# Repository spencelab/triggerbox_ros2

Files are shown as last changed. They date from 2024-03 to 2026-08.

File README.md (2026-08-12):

# To run it
Physical trigger pulses are enabled by default for backward compatibility:
```
ros2 run triggerbox_ros2 triggerbox_host
```
To start with the physical output blanked instead:
```
ros2 run triggerbox_ros2 triggerbox_host \
  --ros-args \
  -p output_enabled_on_start:=false
```
To change the frame rate
```
ros2 service call /triggerbox_host/set_framerate triggerbox_ros2_interfaces/srv/SetFramerate "{data: 250.0}"
```
# Porting to ROS2
## 20260522 Putting v14 on triggerbox arduino off camdev ubuntu 24
Just worked... but more arduino pfaff than would like. And DONT install the full fuse or it reverts you to fuse 2... ooops i did that on my dev machine.
1. Download arduino 2 IDE appimage or zip. put in ~/Applications/Ard...
2. Make the executable executable w permission in gui right click
3. Add yuor user to dialout group and log in log out so you can access serial
4. install the fuse thing and do other thigns to make the IDE work
```
sudo apt install libfuse2t64

cd ~/Applications/arduino-ide_2.3.8_Linux_64bit
sudo chown root:root chrome-sandbox
sudo chmod 4755 chrome-sandbox
ls -l chrome-sandbox

cat > ~/.local/share/applications/arduino-ide-2.desktop <<'EOF'
[Desktop Entry]
Type=Application
Name=Arduino IDE 2
Comment=Arduino development environment
Exec=/home/spencelab/Applications/arduino-ide_2.3.8_Linux_64bit/arduino-ide
Icon=/home/spencelab/Applications/arduino-ide_2.3.8_Linux_64bit/resources/app/resources/icons/512x512.png
Terminal=false
Categories=Development;IDE;Electronics;
StartupNotify=true
EOF

chmod +x ~/.local/share/applications/arduino-ide-2.desktop
update-desktop-database ~/.local/share/applications 2>/dev/null || true

sudo usermod -a -G dialout $USER

#log out, log back in again

Do this:

Open Show Apps
Search Arduino
Right-click Arduino IDE 2
Choose Add to Favorites

That should pin it to the left dock.

./arduino-ide
```

I copied the UDEV library to triggerbox_ros2 repo to ~/Arduino/libraries/UDEV/UDEV.cpp[h] and it just worked and could flash the arduino. 

I pulled the latest triggerbox host and colcon build and it just ran. I use `enable_output` service to turn on pulses. 100Hz works great.

Now on to setting up arduino_udev_ros2 from scratch on this machine. Writing guide on that repo README.

## 20260521 Output Pulse Enable Disable now working for streaming v14 firmware

For continuous recording, we want to start all the camera nodes and put in hardware trigger mode and have them waiting, and then start the pulses from the triggerbox. That way all cameras should start on the same frame no matter when ROS2 messages might arrive, if we did it with software. So we made the patch below and introdcued v14 firmware. Tested at home with oscilloscope with Arduino Nano `trig9`. Also flashed the firmware in Linux using Arduino 2.3.8 IDE AppImage. Needed (Old Bootloader) in Nano spec. 

Also added specifying the device eg `/dev/trig9` in the triggerbox_host launch. Notes in https://chatgpt.com/g/g-p-6a03947397fc8191b3298417bda72197-camera-ros2-contin/c/6a0394fa-c8ec-83ea-a1c0-96703d8dfd53.

Commands to test pulse enable/disable: (trig9=ttyUSB0)
```
~/ros2_ws/src/triggerbox_ros2/scripts/get_triggerbox_name_version /dev/ttyUSB0
ros2 run triggerbox_ros2 triggerbox_host /dev/trig9
ros2 service list | grep triggerbox_host
ros2 topic list | grep output_enabled
ros2 topic echo /triggerbox_host/output_enabled
ros2 service call /triggerbox_host/enable_output std_srvs/srv/Trigger "{}"
# CONFIRMED ON OSCILLOSCOPE 100HZ PULSES on D9 STARTED!
ros2 service call /triggerbox_host/disable_output std_srvs/srv/Trigger "{}"
ros2 service call /triggerbox_host/set_output_enabled std_srvs/srv/SetBool "{data: true}"
ros2 service call /triggerbox_host/set_output_enabled std_srvs/srv/SetBool "{data: false}"
```
Intended rig sequence:
1. Start triggerbox_host.
2. It sets FPS and starts Timer1 clock, but output is blanked.
3. Wait for clock model estimate.
4. Configure/start all camera recorders.
5. Call /triggerbox_host/enable_output.
6. Record.
7. Call /triggerbox_host/disable_output.
8. Stop camera recorders.

## 20260520 Getting to work on fresh ubuntu 24 camdev in lab
1. clone this repo into ros2_ws/src
2. **NEED** to also clone triggerbox_ros2_interfaces
3. then colcon build will do both and you and try with `source install/setup.bash` then `ros2 run triggerbox_ros2 triggerbox_host`.
4. you will likely have errors due to no python serial library OR your user spencelab not having been added to dialout.
5. if former, try `sudo apt install python3-serial`
6. if latter, try `sudo adduser spencelab dialout` and then reboot.
7. This code expects and will exit with error if arduino does not have version 13 firmware. (assert in triggerbox_device.py).
8. I wrote a script in this repo to check if an arduino is flashed with triggerbox by asking for name and version using it's handshaking protocol. it's an executable. call with `./get_triggerbox_name_version` or `./get_triggerbox_name_version /dev/ttyACM0` etc. Gives:

```
spencelab@ros2test:~/ros2_ws/src/triggerbox_ros2/scripts$ ./get_triggerbox_name_version 
Phase 1: udev/name handshake at 9600
name raw: b'trig1\x00\x00\x00DB'
name: trig1
crc ok: True

Phase 2: triggerbox firmware version at 115200
attempt 1: no V packet yet
attempt 2: no V packet yet
attempt 3: no V packet yet
attempt 4: no V packet yet
attempt 5: no V packet yet
attempt 6: no V packet yet
attempt 7: no V packet yet
attempt 8: no V packet yet
attempt 9: no V packet yet
Got V packet on attempt 10
payload length: 7
payload hex: 0D 0A 00 00 00 38 0B
checksum: 5a
version decimal=13, hex=0xD
value=13, pulsenumber=10, ticks=2872
```
9. The firmware included in this triggerbox_ros2 repo is for version 13.
10. In order to flash an arduino with this firmware version from ubuntu 24, you can do the following.
    1. Download install arduino IDE 2.3.8 or newer from arduino, i used appimage, had to properties make executable and `sudo apt install fuse`.
    2. Download the arduino_udev_ros2 repo from spencelab.
    3. Copy the UDEV library from arduino_udev_ros2 into the arduino IDE area `cp -r ~/arduino_udev_ros2/firmware/UDEV ~/Arduino/libraries/`
    4. Restart the IDE, maybe you can build triggerbox.ino?
    5. Yes! It works. I flashed an ancient Arduino Nano from home. It came up as `/dev/ttyUSB0` and caused an ubuntu system error when the UDEV rule failed, but no biggy. Had to choose Processer -> AtMega328P (Old Bootloader) for it to flash, otherwise Arduino IDE fell back to programmger and said no response. Awesome.
    6. Then it will still crash as it reads out garbage from EEPROM as the name 0xFF, but version was correct with new `get_triggerbox...` script. So you just need to set a name with: `arduino-udev-name /dev/ttyUSB0 --set-name trig9 --verbose`. i got back `
RAW: 0x4E 0x3D 0x74 0x72 0x69 0x67 0x39 0x0 0x0 0x0 0x43 0x37 
SET NAME: trig9 (0x74 0x72 0x69 0x67 0x39)
`
    7. The you can ping it! with any script.

```
spencelab@ros2test:~/ros2_ws/src/triggerbox_ros2/scripts$ ./get_triggerbox_name_version /dev/ttyUSB0
Phase 1: udev/name handshake at 9600
name raw: b'trig9\x00\x00\x00C7'
name: trig9
crc ok: True

Phase 2: triggerbox firmware version at 115200
attempt 1: no V packet yet
attempt 2: no V packet yet
attempt 3: no V packet yet
attempt 4: no V packet yet
attempt 5: no V packet yet
attempt 6: no V packet yet
attempt 7: no V packet yet
attempt 8: no V packet yet
attempt 9: no V packet yet
attempt 10: no V packet yet
attempt 11: no V packet yet
Got V packet on attempt 12
payload length: 7
payload hex: 0D 0C 00 00 00 F5 14
checksum: 22
version decimal=13, hex=0xD
value=13, pulsenumber=12, ticks=5365
```
11. You can use triggerbox_host in ROS2 with this package if you identify the triggerbox /dev/ttyACM0 etc. just fine. If you want the fancy mapping to it's given name, so it reliably appears as `/dev/trig2` and you can disambiguate it from eg the treadmill, which is really useful, you need to use arduino_udev and do a few more setup steps. Those are:
## 20260519 Getting to work with cambuffer_recorder_ng

Using arduino from my dev box with red proto board shield on top with driver chip and switch and one bnc.

It is flaky. With switch in 5V position (towards USB in jack) switch needs jiggling for to work. Too much time in bags.

But it will work and trigger the ximea nicely at 100hz.

To start it and change frame rat:
```
ros2 run triggerbox_ros2 triggerbox_host
ros2 service call /triggerbox_host/set_framerate triggerbox_ros2_interfaces/srv/SetFramerate "{data: 25.0}"
```

Figured out with
```
ros2 service type /triggerbox_host/set_framerate
ros2 interface show triggerbox_ros2_interfaces/srv/SetFramerate
```

## 20260521 Pulse Blanking Version 14 Patch and Test Instructions:

https://chatgpt.com/g/g-p-6a03947397fc8191b3298417bda72197/c/6a0394fa-c8ec-83ea-a1c0-96703d8dfd53

Yep, this is the right repo now. I made a focused patch for output blanking while the triggerbox clock keeps running.

Download the triggerbox output-blanking patch

What this adds

Firmware now has:

E0 = disable/blank physical trigger output while Timer1 keeps running
E1 = enable physical trigger output from Timer1

It bumps firmware version from:

13 → 14

so you can confirm the flashed firmware is the new one.

ROS2 host now adds services:

/triggerbox_host/set_output_enabled   std_srvs/srv/SetBool
/triggerbox_host/enable_output        std_srvs/srv/Trigger
/triggerbox_host/disable_output       std_srvs/srv/Trigger
/triggerbox_host/start_clock          std_srvs/srv/Trigger
/triggerbox_host/stop_clock           std_srvs/srv/Trigger

It also publishes:

/triggerbox_host/output_enabled       std_msgs/msg/Bool

Default behavior is:

Timer1 clock runs at configured FPS.
Physical trigger output starts ENABLED by default for backward compatibility.
The Timer1 clock and physical trigger pulses therefore begin immediately after startup/configuration.
Newer camera-control workflows may temporarily blank the physical output with disable_output and restore it with enable_output.

To opt into the former blanked-at-start behavior, launch with:

ros2 run triggerbox_ros2 triggerbox_host --ros-args -p output_enabled_on_start:=false
Branch and apply
cd ~/ros2_ws/src/triggerbox_ros2

git status
git switch main
git pull origin main

git switch -c output-blanking-clock-run
unzip -o /path/to/triggerbox_ros2_output_blanking_patch.zip

Build:

cd ~/ros2_ws

colcon build --packages-select triggerbox_ros2 \
  --event-handlers console_direct+

source install/setup.bash
Flash firmware

Copy/install the updated firmware/triggerbox/triggerbox.ino to Arduino IDE or open it directly.

After flashing, your checker should report:

version decimal=14, hex=0xE
Test services

Start host:

ros2 run triggerbox_ros2 triggerbox_host

Confirm services:

ros2 service list | grep triggerbox_host
ros2 topic list | grep output_enabled

Check output state:

ros2 topic echo /triggerbox_host/output_enabled

Enable physical trigger pulses:

ros2 service call /triggerbox_host/enable_output std_srvs/srv/Trigger "{}"

Disable physical trigger pulses:

ros2 service call /triggerbox_host/disable_output std_srvs/srv/Trigger "{}"

Or set directly:

ros2 service call /triggerbox_host/set_output_enabled std_srvs/srv/SetBool "{data: true}"
ros2 service call /triggerbox_host/set_output_enabled std_srvs/srv/SetBool "{data: false}"

Clock controls, mostly for debugging:

ros2 service call /triggerbox_host/start_clock std_srvs/srv/Trigger "{}"
ros2 service call /triggerbox_host/stop_clock std_srvs/srv/Trigger "{}"
Current rig behavior
1. Start triggerbox_host.
2. It sets FPS, starts Timer1, and enables physical trigger output by default.
3. Camera-control can blank output with /triggerbox_host/disable_output to define one shared hardware endpoint for synchronized RAM-buffer dumps.
4. After every camera finishes the dump write, camera-control calls /triggerbox_host/enable_output and acquisition continues.
Notes

This patch does not require changes to triggerbox_ros2_interfaces; it uses standard ROS services from std_srvs.

The default is now pulses on for backward compatibility with older acquisition software. Newer camera-control workflows explicitly blank and restore output around synchronized RAM-buffer dumps.

### Lots of fun profiling on hardware trigger.

Trying to get the thread rt priority:
```
spencelab@ros2test:~/ros2_ws$ sudo groupadd -f realtime
[sudo] password for spencelab: 
spencelab@ros2test:~/ros2_ws$ sudo usermod -aG realtime $USER
spencelab@ros2test:~/ros2_ws$ sudo tee /etc/security/limits.d/99-realtime.conf >/dev/null <<'EOF'
> @realtime   -   rtprio     80
@realtime   -   memlock    unlimited
@realtime   -   nice       -10
EOF
spencelab@ros2test:~/ros2_ws$ cat /etc/security/limits.d/99-realtime.conf 
@realtime   -   rtprio     80
@realtime   -   memlock    unlimited
@realtime   -   nice       -10
spencelab@ros2test:~/ros2_ws$ 
```

You need to reboot, but **THAT WORKS** and on reboot, running in terminal with no browser open, it dumps to disk with 16 frame ximea buffer and we had ZERO frame drops at the camera for 30 seconds or a minute or so. GREAT! And even cooler you can see the buffer working. camera triggers are on sync but a lag in disk writing follow by catching up!



See it should be around 10ms, it lags off to 47ms and then a series of 1ms writes catch up!

## Older work
1. Just get triggerbox_device.py to work in Python3
2. On Spence mac...
3. pip3 install ... no it says use brew... brew... tricky... so

```
conda create -f triggerbox_ros2
conda activate triggerbox_ros2
conda install pyserial numpy
python3 triggerbox_device.py /dev/tty.usbmodem1101 
```

Made Queue queue for python3...
exceptions parentheses...

4. Copied arduinoudev.py from our forked repo into '/Users/aspence/miniconda3-arm64/envs/triggerbox_ros2/lib/python3.12/site-packages/arduinoudev.py' because lazy. It has a setup.py... you could probably conda install from setup.py the package and it would put there for you...
5. It runs! Fixing all the Queue to queue...
6. 

## Getting running on the lenovo box with trig5 arduino

1. Forgot to commit setup.cfg so it couldnt' find triggerbox_host executable... fixed.
2. Didn't have serial... did

```
spencelab@ros2test:~/ros2_ws$ rosdep install --from-paths src -y --ignore-src
executing command [sudo -H apt-get install -y python3-serial]
Reading package lists... Done
Building dependency tree... Done
Reading state information... Done
Suggested packages:
  python3-wxgtk3.0 | python3-wxgtk
The following NEW packages will be installed:
  python3-serial
0 upgraded, 1 newly installed, 0 to remove and 0 not upgraded.
Need to get 78.7 kB of archives.
After this operation, 470 kB of additional disk space will be used.
Get:1 http://us.archive.ubuntu.com/ubuntu jammy/main amd64 python3-serial all 3.5-1 [78.7 kB]
Fetched 78.7 kB in 0s (268 kB/s)          
Selecting previously unselected package python3-serial.
(Reading database ... 294264 files and directories currently installed.)
Preparing to unpack .../python3-serial_3.5-1_all.deb ...
Unpacking python3-serial (3.5-1) ...
Setting up python3-serial (3.5-1) ...
#All required rosdeps installed successfully
```
### Access to serial port
Gah close need to do that dialout group user add jawn probably

```
serial.serialutil.SerialException: [Errno 13] could not open port /dev/ttyACM0: [Errno 13] Permission denied: '/dev/ttyACM0'
Traceback (most recent call last):
```
Fixed!

Find your groups `groups spencelab`

Does not include dialout.

`sudo adduser spencelab dialout`

**REBOOT** the machine! Logging in and out is not enough!

New error...

### It's running!

But I think my topics are missing the node name in front etc. ALSO must always remember to `. install/setup.bash`!

So i get now: (NOTES ABOUT THIS: I HAD HARDCODED NEW TOPIC NAMES WITH NO BASE. NOW Fixed below.).
```
spencelab@ros2test:~/ros2_ws$ . install/setup.bash 
spencelab@ros2test:~/ros2_ws$ ros2 topic list
/aout_confirm
/aout_raw
/aout_volts
/expected_framerate
/parameter_events
/pause_and_reset
/raw_measurements
/rosout
/set_triggerrate
/time_model
spencelab@ros2test:~/ros2_ws$ ros2 topic list -t
/aout_confirm [triggerbox_ros2_interfaces/msg/AOutConfirm]
/aout_raw [triggerbox_ros2_interfaces/msg/AOutRaw]
/aout_volts [triggerbox_ros2_interfaces/msg/AOutVolts]
/expected_framerate [std_msgs/msg/Float32]
/parameter_events [rcl_interfaces/msg/ParameterEvent]
/pause_and_reset [std_msgs/msg/Float32]
/raw_measurements [triggerbox_ros2_interfaces/msg/TriggerClockMeasurement]
/rosout [rcl_interfaces/msg/Log]
/set_triggerrate [std_msgs/msg/Float32]
/time_model [triggerbox_ros2_interfaces/msg/TriggerClockModel]
spencelab@ros2test:~/ros2_ws$ ros2 topic echo /raw_measurements 
start_timestamp: 1712791137.2870135
pulsenumber: 10550
fraction_n_of_255: 110
stop_timestamp: 1712791137.2923086
---
start_timestamp: 1712791138.2945035
pulsenumber: 10650
fraction_n_of_255: 18
stop_timestamp: 1712791138.2998571
---
start_timestamp: 1712791139.3024065
pulsenumber: 10751
fraction_n_of_255: 191
stop_timestamp: 1712791139.3076122
---
start_timestamp: 1712791140.3100817
pulsenumber: 10852
fraction_n_of_255: 103
stop_timestamp: 1712791140.3148384
---
start_timestamp: 1712791141.318424
pulsenumber: 10953
fraction_n_of_255: 33
stop_timestamp: 1712791141.3223727
---
^Cspencelab@ros2test:~/ros2_ws$ ros2 topic echo /time_model
gain: 0.010010829431015212
offset: 1712791031.6713433
---
gain: 0.010010877060864001
offset: 1712791031.671114
---
gain: 0.01001086394535979
offset: 1712791031.6712198
---
gain: 0.010010850077359702
offset: 1712791031.6713362
---

```

But this page makes me think I should have node names before topics etc. (https://docs.ros.org/en/humble/Tutorials/Beginner-CLI-Tools/Understanding-ROS2-Topics/Understanding-ROS2-Topics.html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)

YES! For rqt to see your custom message types and thus display them in the topic monitor you must do `. install/setup.bash` before `rqt` then it works.

It's publishing to /time_model

### 2025-06-30 Re-up working!

Ok I tried to do this again and had some issues with make_ros_topic - it was trying to make a topci `~time_model` in old school ros1 and ros2 requires the slash `~/time_model`. So i deleted the bit in make_ros_topic in triggerbox_host i believe so it just always adds slash, and it works! In ubuntu 22 on the testing lenovo. i flashed a freqsh v=13 firmware triggerbox onto the vilros test plate that had a EMG board on it. works great. i get:

```
spencelab@ros2test:~/ros2_ws/src/triggerbox_ros2$ ros2 run triggerbox_ros2 triggerbox_host 
INFO:trigger.device:Waiting until serial device confirmed...
INFO:root.serial:connected to device named ''
INFO:root.serial:checking firmware version
INFO:root.serial:checking firmware version
INFO:root.serial:checking firmware version
INFO:root.serial:checking firmware version
INFO:root.serial:checking firmware version
INFO:root.serial:checking firmware version
INFO:root.serial:checking firmware version
INFO:root.serial:checking firmware version
INFO:root.serial:checking firmware version
INFO:root.serial:connected to triggerbox firmware version 13
WARNING:root.serial:No clock measurements until framerate set.
[INFO] [1751303284.935785077] [triggerbox_host]: triggerbox_host: connected to 'v:13' on device '/dev/ttyACM0'
[INFO] [1751303284.937879748] [triggerbox_host]: triggerbox_host: setting FPS to 100.0
INFO:trigger.device:received set_triggerrate command with target of 100.0
[INFO] [1751303284.938357361] [triggerbox_host]: Got clock model
INFO:trigger.device:desired rate 100.0 (actual rate 100.0) using ICR1_AND_PRESCALER 0x9C4 64
[INFO] [1751303284.944930972] [triggerbox_host]: Got clock model
[INFO] [1751303284.945395432] [triggerbox_host]: triggerbox_host: waiting for clockmodel estimate
[INFO] [1751303285.447141439] [triggerbox_host]: triggerbox_host: waiting for clockmodel estimate
[INFO] [1751303285.949792132] [triggerbox_host]: triggerbox_host: waiting for clockmodel estimate
[INFO] [1751303286.452211598] [triggerbox_host]: triggerbox_host: waiting for clockmodel estimate
[INFO] [1751303286.954629185] [triggerbox_host]: triggerbox_host: waiting for clockmodel estimate
[INFO] [1751303287.456994117] [triggerbox_host]: triggerbox_host: waiting for clockmodel estimate
[INFO] [1751303287.959343659] [triggerbox_host]: triggerbox_host: waiting for clockmodel estimate
[INFO] [1751303288.460215038] [triggerbox_host]: triggerbox_host: waiting for clockmodel estimate
[INFO] [1751303288.897180485] [triggerbox_host]: Got clock model
DEBUG:trigger.device:approximate timer frequency: 99.89752418542193
[INFO] [1751303288.962573438] [triggerbox_host]: triggerbox_host: got clockmodel estimate
[INFO] [1751303289.910580327] [triggerbox_host]: Got clock model
DEBUG:trigger.device:approximate timer frequency: 99.88166720912373
[INFO] [1751303290.922867025] [triggerbox_host]: Got clock model
DEBUG:trigger.device:approximate timer frequency: 99.89321736840478
[INFO] [1751303291.936306345] [triggerbox_host]: Got clock model
DEBUG:trigger.device:approximate timer frequency: 99.88989040058513
[INFO] [1751303292.849422258] [triggerbox_host]: Got clock model
DEBUG:trigger.device:approximate timer frequency: 99.89887679263718
[INFO] [1751303293.863421914] [triggerbox_host]: Got clock model
DEBUG:trigger.device:approximate timer frequency: 99.89064213871087
[INFO] [1751303294.874911549] [triggerbox_host]: Got clock model
DEBUG:trigger.device:approximate timer frequency: 99.88857880865557
[INFO] [1751303295.888662594] [triggerbox_host]: Got clock model
DEBUG:trigger.device:approximate timer frequency: 99.89177746523458
[INFO] [1751303296.902946154] [triggerbox_host]: Got clock model
DEBUG:trigger.device:approximate timer frequency: 99.88764501523428
[INFO] [1751303297.917656235] [triggerbox_host]: Got clock model
DEBUG:trigger.device:approximate timer frequency: 99.88722978585729
[INFO] [1751303298.931940264] [triggerbox_host]: Got clock model
DEBUG:trigger.device:approximate timer frequency: 99.88824280233169
[INFO] [1751303299.946035008] [triggerbox_host]: Got clock model
DEBUG:trigger.device:approximate timer frequency: 99.88938141739722
[INFO] [1751303300.960263708] [triggerbox_host]: Got clock model
DEBUG:trigger.device:approximate timer frequency: 99.88931348767154
[INFO] [1751303301.972255338] [triggerbox_host]: Got clock model
DEBUG:trigger.device:approximate timer frequency: 99.88918245366627
[INFO] [1751303302.985092249] [triggerbox_host]: Got clock model
DEBUG:trigger.device:approximate timer frequency: 99.88966828749199
[INFO] [1751303303.998031260] [triggerbox_host]: Got clock model
DEBUG:trigger.device:approximate timer frequency: 99.88779585205677
[INFO] [1751303305.010649616] [triggerbox_host]: Got clock model
DEBUG:trigger.device:approximate timer frequency: 99.88689567203292
[INFO] [1751303306.024470742] [triggerbox_host]: Got clock model
DEBUG:trigger.device:approximate timer frequency: 99.88701791387936
[INFO] [1751303307.040632250] [triggerbox_host]: Got clock model
DEBUG:trigger.device:approximate timer frequency: 99.88776427283234
```

Now examining the topics: in second terminal:

```
spencelab@ros2test:~$ ros2 topic list
/parameter_events
/rosout
/triggerbox_host/aout_confirm
/triggerbox_host/aout_raw
/triggerbox_host/aout_volts
/triggerbox_host/expected_framerate
/triggerbox_host/pause_and_reset
/triggerbox_host/raw_measurements
/triggerbox_host/set_triggerrate
/triggerbox_host/time_model
```

works! to see need . install:

```
spencelab@ros2test:~$ ros2 topic echo /triggerbox_host/time_model 
The message type 'triggerbox_ros2_interfaces/msg/TriggerClockModel' is invalid
spencelab@ros2test:~$ pwd
/home/spencelab
spencelab@ros2test:~$ cd ros2_ws/
spencelab@ros2test:~/ros2_ws$ . install/setup.
bash: install/setup.: No such file or directory
spencelab@ros2test:~/ros2_ws$ . install/setup.bash 
spencelab@ros2test:~/ros2_ws$ ros2 topic list
/parameter_events
/rosout
/triggerbox_host/aout_confirm
/triggerbox_host/aout_raw
/triggerbox_host/aout_volts
/triggerbox_host/expected_framerate
/triggerbox_host/pause_and_reset
/triggerbox_host/raw_measurements
/triggerbox_host/set_triggerrate
/triggerbox_host/time_model
spencelab@ros2test:~/ros2_ws$ ros2 topic echo /triggerbox_host/time_model 
gain: 0.010011299331848193
offset: 1751303552.5350645
---
gain: 0.010011296453507578
offset: 1751303552.5350807
---
gain: 0.010011285478196099
offset: 1751303552.5351677
---
gain: 0.01001133854431243
offset: 1751303552.534838
```

### 2025-06-27 Spence using to test and set up big grey triggerbox with 8 bncs and IR

See the Strawlab_triggerbox wiki page on aspence/spencelab wiki for details. Basically flashed the firmware, changed to trig2, which based on the merb launch file might match the box there, helping with direct swap. Also confirmed in the launch file we want to run a triggerbox_host.

Using the ubuntu 22 test lenovo box, was able to set it's name, and python3 triggerbox_device, but when i did

```
cd ros2_ws
. install/setup.bash
ros2 run triggerbox_ros2 triggerbox_host
```

I get an error about an invalid topic name becuase of a ~. But my notes above suggest I had it working. How? Where?

```
In ROS 2, a topic name starting with a tilde (~) signifies a private namespace. This means the topic name will be resolved relative to the node's name, essentially using the node's name as a namespace. For instance, if you have a node named my_node and you publish to a topic named ~topic, the actual topic name will be /my_node/topic. 
However, the ROS 2 documentation mentions a specific rule for topic names starting with a tilde: they must be separated from the rest of the name with a forward slash (/). So, the correct syntax is ~/foo and not ~foo. This rule is in place to prevent inconsistencies with how ~foo is interpreted in filesystem paths. 
Therefore, the error you are encountering with ros2 topic likely stems from using ~nodename instead of ~/nodename when specifying a private topic name. You need to include the forward slash after the tilde to indicate a private namespace.
In summary:
~ indicates a private namespace, according to Duckietown.
~/topic_name is the correct syntax for a private topic, according to ROS2 Design.
Without the forward slash (~), ROS 2 might interpret the tilde differently or throw an error due to the syntax rule. 
To fix the issue, ensure you are using the correct syntax ~/topic_name when referring to private topics within ros2 topic commands.
```

Well I dont want a private name space. And above I said it was publishing to /time_model. I think the problem is that we are trying to create a bunch of `~time_model` type topics and that's not allowed in ROS2. Was it in ROS1?

```
def _make_ros_topic(base, other):
    if base == '~':
        return base+other

    #ensure no start slash and one trailing slash
    if base[0] == '/':
        base = base[1:]
    if base[-1] == '/':
        base = base[:-1]

    return base + '/' + other
```

I think it should just be /triggerbox_host/time_model etc? Above i just had /time_model in the root space. What do I get in the normal working ROS1 space?

See here:
https://github.com/aspence/spencelab/wiki/Ubuntu-22-Jammy-ROS-2-Humble-Testing

Yeah on ROS1 we get /triggerbox_node/time_model etc:

how and why? base name gets set to triggerbox_node. launch file? Yep looks like it:

from a ros 1 launch file:

```
- <node machine="tmill4merb" name="triggerbox_node" pkg="triggerbox"
    type="triggerbox_host" args="--device /dev/trig2" />
```

Now is the ros1 triggerbox_host.py code differetn wrt base name? No... but initializing different.

Maybe ROS1 takes ~time_model and makes it /NODE_NAME/time_model

I FIXED ALL ABOVE SEE ABOVE. Just commented out the base combine thing without ~. It just worked.

## Trigger output blanking

Firmware version 14 adds a physical trigger-output gate. The Timer1 clock can
run while the camera trigger pin is blanked. The firmware itself now powers
up with physical trigger output enabled for legacy-system compatibility; E0
still blanks output and E1 restores it without resetting the clock.

ROS 2 services exposed by `triggerbox_host`:

```bash
ros2 service call /triggerbox_host/set_output_enabled std_srvs/srv/SetBool "{data: false}"
ros2 service call /triggerbox_host/enable_output std_srvs/srv/Trigger "{}"
ros2 service call /triggerbox_host/disable_output std_srvs/srv/Trigger "{}"
ros2 service call /triggerbox_host/start_clock std_srvs/srv/Trigger "{}"
ros2 service call /triggerbox_host/stop_clock std_srvs/srv/Trigger "{}"
```

By default `triggerbox_host` starts with `output_enabled_on_start:=true`: the
timer runs at the configured frame rate and physical trigger pulses are emitted
immediately, matching legacy triggerbox behavior. To deliberately start blanked:

```bash
ros2 run triggerbox_ros2 triggerbox_host --ros-args -p output_enabled_on_start:=false
```

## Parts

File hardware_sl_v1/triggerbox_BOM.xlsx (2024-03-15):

Spence Lab Triggerbox Hardware BOM
All versions
Arduino Nano A000005
Laser cut panels at Ponoko |  |  | https://help.ponoko.com/en/articles/2688477-what-design-software-file-type-should-i-use
Variable DC power supply |  |  | https://www.amazon.com/Adjustable-Universal-Switching-100V-240V-Electronics/dp/B09NN4WTXK (https://nam10.safelinks.protection.outlook.com/?reserved=0) | ORDERED 2 GAVE 1 SD TEAM
28V 500mA DC wall wart 5.5mm plug |  |  | https://www.amazon.com/QKKE-Switching-Supply-Adapter-100V-240V/dp/B089T5FJXX | 11
28V 3A DC wall wart 5.5 by 2.1 or 2.5mm |  |  | https://www.amazon.com/28V-3A-Adaptor-Adapter-Charger/dp/B07F5G4CT4 | 20
5V 1A DC supply inc 5.5mm plug |  |  | https://www.amazon.com/Arkare-100V-240V-Replacement-Security-Raspberry-Pi/dp/B09W8X9VGK?s=electronics
DC 2.1mm power jack breadboard friendly |  |  | https://www.adafruit.com/product/373
DC 2.5mm to 2.1mm adapter |  |  | https://www.adafruit.com/product/2897
Breadboard
Tested complex op-amp version… worked
Tested single MOSFET 2N7000 version… worked but floating signal not great
Tested TBD62783 driver version, works really great
Arduino UNO with Protoshield w BNC and 3D print enclosure
Arduino UNO R3
GIKFUN Proto Shield |  |  | https://www.amazon.com/Gikfun-Prototype-Shield-Arduino-Ek1038x3/dp/B00Q9YB7PI
TBD62783APG | 8 channel DMOS transistor array |  | https://www.digikey.com/en/products/detail/toshiba-semiconductor-and-storage/TBD62783APG/5514092 | 1.63 | 10 |  | 18 dip
SPDT proto compat switch from EMG spikershield
Variable DC power supply wall wart |  |  | https://www.amazon.com/Adjustable-Universal-Switching-100V-240V-Electronics/dp/B09NN4WTXK (https://nam10.safelinks.protection.outlook.com/?reserved=0) | ORDERED 2 GAVE 1 SD TEAM
Protoboard panel mount
item | description | partnumber | url | cost | count | total | package
TBD62783APG | 8 channel DMOS transistor array |  | https://www.digikey.com/en/products/detail/toshiba-semiconductor-and-storage/TBD62783APG/5514092 | 1.63 | 10 |  | 18 dip
SN74HC125N | quad buffer 6V |  | https://www.digikey.com/en/products/detail/texas-instruments/SN74HC125N/277218 | 0.96 | 10 |  | 14 CDIP | 0.3
Panel mount BNC jack |  |  | https://www.digikey.com/en/products/detail/te-connectivity-amp-connectors/5227755-2/813452 | 3.31 | 10
DC power supply 28V, 5V | get barrel jack sizes
barrel jack that fits both
PCB
Slide in enclosure |  |  | https://www.polycase.com/ex-65
https://www.polycase.com/ex-series | Cyclops was 125mm wide by 80mm deep
 | About 5x3 inches.
Gold 170mm wide x 80mm deep |  |  | https://www.amazon.com/B4-160BL-Anodized-Extruded-Electronic-Enclosure/dp/B07MZP31QC?s=hi | 33
Newark |  | B5-080BK | https://www.newark.com/box-enclosures/b5-080bk/enclosure-instrument-aluminium/dp/39M5412 |  |  |  |  |  |  | https://www.newark.com/box-enclosures/b5-080si/enclosure-instrument-aluminium/dp/39M5414
Amazon blue one |  |  | https://www.amazon.com/B5-160BK-Anodized-Extruded-Electronic-Enclosure/dp/B07MZPRQ78
Amazon gold one | 125mm wide x 80mm PCB | B5-080GD | https://www.amazon.com/B5-080GD-Anodized-Extruded-Electronic-Enclosure/dp/B07MZPBPFL?th=1
TLP-292-4 | Opto-couplers | TLP292-4 | https://www.digikey.com/en/products/detail/toshiba-semiconductor-and-storage/TLP292-4-TP-E/5215705
Arduino UNO Proto Shield 5V Buffers V1
Arduino Proto Shield |  |  | https://www.digikey.com/en/products/detail/arduino/TSX00083/9486718
Adafruit Arduino Proto Shield (better) |  |  | https://www.adafruit.com/product/2077 | 10 | 3 |  |  | https://www.digikey.com/en/products/detail/adafruit-industries-llc/2077/5353667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
TLV9054IDR | rail to rail input and doutput |  | https://www.digikey.com/en/products/detail/texas-instruments/TLV9054IDR/10273198
SOIC 8 breakouts for breadboard, proto board
Adafruit parts 1206 to 1212 SOIC breakouts and 1230 why not
OPA340PA. - UA newer | rail to rail input and output, DIP package, dual
OPA365
OK WAIT DOING IT WITH OP-AMPS IS DUMB DUE TO RAIL TO RAIL AND INPUT OFFSET ISSUES. JUST USE A TRANSISTOR.
2N7000 sweet MOSFET transistor we have in jameco droors |  | acts as a low value resistor when open! |  |  |  |  |  |  | http://squirrelengineering.com/baby-squirrels/baby-squirrels-a-simple-transistor-switch-circuit/
Breadboard/proto compatible BNC |  |  | https://www.amazon.com/Atlas-Scientific-Pre-Assembled-Female-BNC/dp/B07NP5XXG3

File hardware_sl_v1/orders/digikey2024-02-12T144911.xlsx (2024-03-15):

Index | Quantity | Part Number | Manufacturer Part Number | Description | Customer Reference | Available | Backorder | Unit Price | Extended Price USD
1 | 10 | TBD62783APG-ND | TBD62783APG | IC PWR SWITCH P-CHAN 1:1 18DIP |  | 10 | 0 | 1.63 | 16.30 | https://www.digikey.com/en/products/detail/toshiba-semiconductor-and-storage/TBD62783APG/5514092
2 | 10 | 296-1572-5-ND | SN74HC125N | IC BUFFER NON-INVERT 6V 14DIP |  | 10 | 0 | 0.861 | 8.61 | https://www.digikey.com/en/products/detail/texas-instruments/SN74HC125N/277218
3 | 10 | A32343-ND | 5227755-2 | CONN BNC RCPT STR 50 OHM SOLDER |  | 10 | 0 | 3.312 | 33.12 | https://www.digikey.com/en/products/detail/te-connectivity-amp-connectors/5227755-2/813452

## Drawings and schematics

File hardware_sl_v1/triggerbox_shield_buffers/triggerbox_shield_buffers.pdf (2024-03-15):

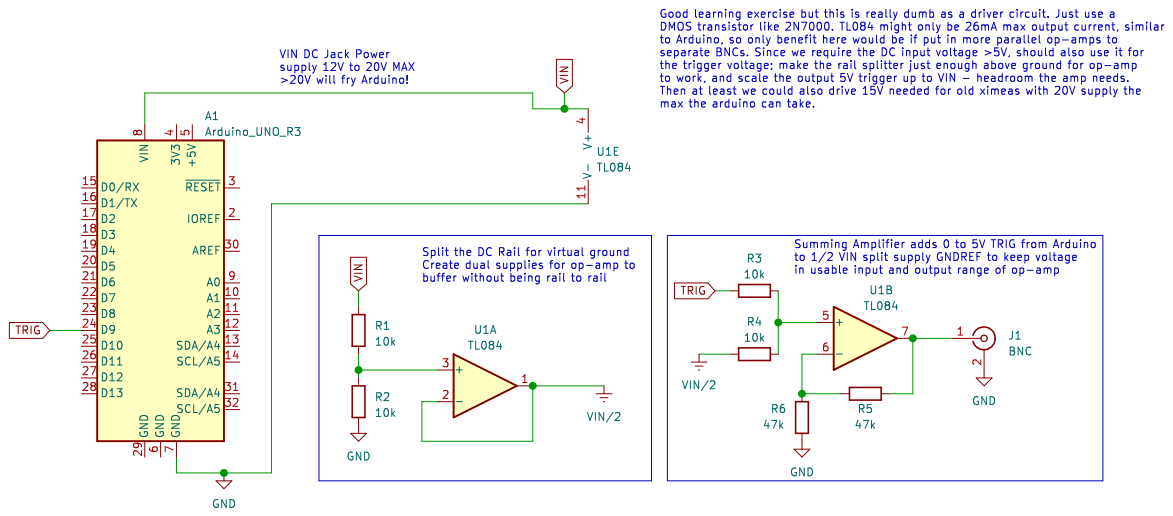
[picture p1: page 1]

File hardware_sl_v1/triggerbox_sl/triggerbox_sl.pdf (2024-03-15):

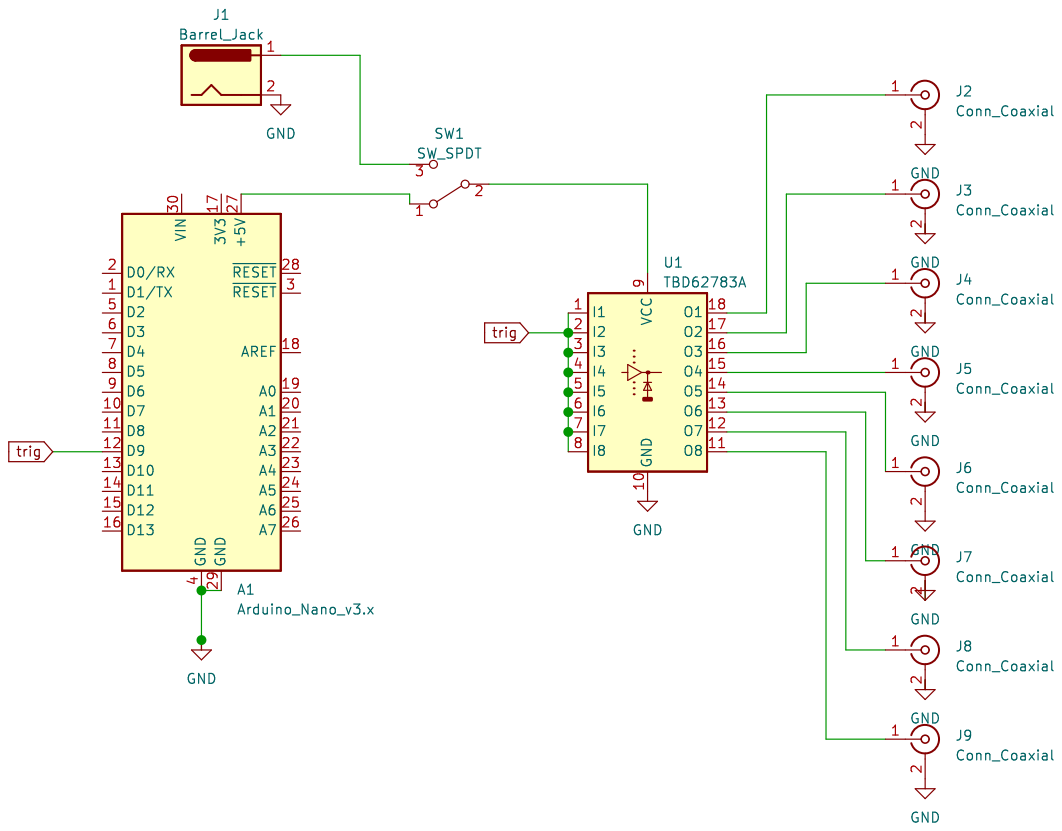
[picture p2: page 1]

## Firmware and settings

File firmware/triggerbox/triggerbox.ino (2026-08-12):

/* -*- Mode: C++; tab-width: 4; indent-tabs-mode: nil; c-basic-offset: 4 -*-

triggerbox - trigger box for arduino
====================================

This file contains the source code for the firmware that runs on the
Arduino device. There are two notable things that happen here.


Regular hardware trigger pulse generation
-----------------------------------------

We need to send trigger pulses at a regular interval.

Clock synchronization support
-----------------------------

See the file synchronization.md for information about the theory of
operation. In this firmware, we need to respond to clock requests with
our current clock value. We use the device's timer1 as our official
clock.

 */

#include <Arduino.h>
#include <EEPROM.h>
#include <SPI.h>
#include <UDEV.h>

#define WITH_AOUT
#ifdef WITH_AOUT

// ----------------------- start MCP4822 library

/* This MCP4822 code is included in this file so the whole firmware
   can be distributed as a single Arduino file without having to
   install libraries. It was originally written by Will Dickson, IO
   Rodeo Inc. It was downloaded from
   https://bitbucket.org/iorodeo/iorodeo_arduino_libs . It is licensed
   under the Apache 2.0 licence.

*/

#define MCP4822_NUMCHAN 2

enum MCP4822_DAC_CHAN {MCP4822_DAC_A, MCP4822_DAC_B};

class MCP4822 {
private:
    int cs;
    int ldac;
    int gain[MCP4822_NUMCHAN];
    int getCmdWrd(int dac, int value);
public:
    MCP4822();
    MCP4822(int csPin, int ldacPin);
    void setValue(int dac, int value);
    void setValue_A(int value);
    void setValue_B(int value);
    void setValue_AB(int value_A, int value_B);
    void setGain2X(int dac);
    void setGain2X_A();
    void setGain2X_B();
    void setGain2X_AB();
    void setGain1X(int dac);
    void setGain1X_A();
    void setGain1X_B();
    void setGain1X_AB();
    void off_AB();
    void off_A();
    void off_B();
    void off(int dac);
};
// ----------------------------------------------------------------------------
// max4822.cpp
//
// Provides an SPI based interface to the MCP4822 dual voltage output digital
// to analog converter.
//
// Author: Will Dickson, IO Rodeo Inc.
// ----------------------------------------------------------------------------

#define ACTIVE      0b0001000000000000
#define SHUTDOWN    0b0000000000000000
#define GAIN_2X     0b0000000000000000
#define GAIN_1X     0b0010000000000000
#define DAC_A_WRITE 0b0000000000000000
#define DAC_B_WRITE 0b1000000000000000

MCP4822::MCP4822() {
}

// ----------------------------------------------------------------------------
// MCP4822::MCP4822
//
// Constructor
// ----------------------------------------------------------------------------
MCP4822::MCP4822(int csPin, int ldacPin) {
    // Configure chip select and latch pins
    cs = csPin;
    ldac = ldacPin;
    pinMode(cs,OUTPUT);
    pinMode(ldac,OUTPUT);
    digitalWrite(cs,HIGH);
    digitalWrite(ldac,HIGH);
    // Set to default configuration
    setGain2X_AB();
}

// ---------------------------------------------------------------------------
// MCP4822::getCmdWrd
//
// Gets command work for writing value to given channel
// ---------------------------------------------------------------------------
int MCP4822::getCmdWrd(int dac, int value) {
    int cmdWrd = 0;
    switch (dac) {
        case MCP4822_DAC_A:
            cmdWrd = DAC_A_WRITE;
            break;
        case MCP4822_DAC_B:
            cmdWrd = DAC_B_WRITE;
            break;
        default:
            return 0;
    }
    cmdWrd |= gain[dac];
    cmdWrd |= ACTIVE;
    cmdWrd |= (0b0000111111111111 & value);
    return cmdWrd;
}

// ----------------------------------------------------------------------------
// MCP4822::setValue
//
// Set the output value of the given dac channel
// ----------------------------------------------------------------------------
void MCP4822::setValue(int dac, int value) {
    int cmdWrd;
    uint8_t byte0;
    uint8_t byte1;

    // Enable SPI communications
    digitalWrite(cs,LOW);
    // Send command word
    cmdWrd = getCmdWrd(dac,value);
    byte0 = cmdWrd >> 8;
    byte1 = cmdWrd & 0b0000000011111111;
    SPI.transfer(byte0);
    SPI.transfer(byte1);
    // Disable SPI communications
    digitalWrite(cs,HIGH);
    // Latch value
    digitalWrite(ldac,LOW);
    digitalWrite(ldac,HIGH);
}

// ---------------------------------------------------------------------------
// MCP4822::setValue_A
//
// Set the output value of dac A to the given value
// ---------------------------------------------------------------------------
void MCP4822::setValue_A(int value) {
    setValue(MCP4822_DAC_A, value);
}

// ----------------------------------------------------------------------------
// MCP4822::setValue_B
//
// Set the output value of dac B to the given value
// ----------------------------------------------------------------------------
void MCP4822::setValue_B(int value) {
    setValue(MCP4822_DAC_B,value);
}

// ---------------------------------------------------------------------------
// MCP4822::setValue_AB
//
// Set the output value of dac A and B to the given values. Latch them in at
// the same time.
// ---------------------------------------------------------------------------
void MCP4822::setValue_AB(int value_A, int value_B) {
    int cmdWrd;
    uint8_t byte0;
    uint8_t byte1;
    // Enable SPI communications and send command word
    digitalWrite(cs,LOW);
    // Send command word for DAC A
    cmdWrd = getCmdWrd(MCP4822_DAC_A,value_A);
    byte0 = cmdWrd >> 8;
    byte1 = cmdWrd & 0b0000000011111111;
    SPI.transfer(byte0);
    SPI.transfer(byte1);
    // Toggle CS
    digitalWrite(cs,HIGH);
    digitalWrite(cs,LOW);
    // Send command word for DAC A
    cmdWrd = getCmdWrd(MCP4822_DAC_B,value_B);
    byte0 = cmdWrd >> 8;
    byte1 = cmdWrd & 0b0000000011111111;
    SPI.transfer(byte0);
    SPI.transfer(byte1);
    // Disable SPI communications
    digitalWrite(cs,HIGH);
    // Latch value
    digitalWrite(ldac,LOW);
    digitalWrite(ldac,HIGH);

}

// ---------------------------------------------------------------------------
// MCP4822::setGain2X
//
// Set the gain of the given channel to 2X
// ---------------------------------------------------------------------------
void MCP4822::setGain2X(int dac) {
    if ((dac == MCP4822_DAC_A) || (dac == MCP4822_DAC_B)) {
        gain[dac] = GAIN_2X;
    }
}

// ----------------------------------------------------------------------------
// MCP4822::setGain2X_A
//
// Set the gain of dac A to 2X
// ----------------------------------------------------------------------------
void MCP4822::setGain2X_A() {
    setGain2X(MCP4822_DAC_A);
}

// ----------------------------------------------------------------------------
// MCP4822::setGain2X_B
//
// Set the gain of dac B to 2X
// ----------------------------------------------------------------------------
void MCP4822::setGain2X_B() {
    setGain2X(MCP4822_DAC_B);
}

// ----------------------------------------------------------------------------
// MCP4822::setGain2X_AB
//
// Set the gain of dac A and B to 2X
// ----------------------------------------------------------------------------
void MCP4822::setGain2X_AB() {
    setGain2X_A();
    setGain2X_B();
}

// ---------------------------------------------------------------------------
// MCP4822::setGain1X
//
// Set the gain of the given channel to 1X
// ----------------------------------------------------------------------------
void MCP4822::setGain1X(int dac) {
    if ((dac == MCP4822_DAC_A) || (dac == MCP4822_DAC_B)) {
        gain[dac] = GAIN_1X;
    }
}

// ----------------------------------------------------------------------------
// MCP4822::setGain1X_A
//
// Set the gain of dac A to 1X
// ----------------------------------------------------------------------------
void MCP4822::setGain1X_A() {
    setGain1X(MCP4822_DAC_A);
}

// ----------------------------------------------------------------------------
// MCP4822::setGain1X_B
//
// Set the gain of dac B to 1X
// ----------------------------------------------------------------------------
void MCP4822::setGain1X_B() {
    setGain1X(MCP4822_DAC_B);
}

// ----------------------------------------------------------------------------
// MCP4822::setGain1X_AB
//
// Set the gain of dac A and B to 1X
// ----------------------------------------------------------------------------
void MCP4822::setGain1X_AB() {
    setGain1X_A();
    setGain1X_B();
}

// ----------------------------------------------------------------------------
// MCP4822::off
//
// Turn off the given dac
// ----------------------------------------------------------------------------
void MCP4822::off(int dac) {
    int cmdWrd = 0;
    uint8_t byte0;
    uint8_t byte1;

    // Create shutdown cmd word.
    switch (dac) {
        case MCP4822_DAC_A:
            cmdWrd = DAC_A_WRITE;
            break;
        case MCP4822_DAC_B:
            cmdWrd = DAC_B_WRITE;
            break;
        default:
            return;
    }
    cmdWrd |= SHUTDOWN;
    // Enable SPI communications
    digitalWrite(cs,LOW);
    // Send command word
    byte0 = cmdWrd >> 8;
    byte1 = cmdWrd & 0b0000000011111111;
    SPI.transfer(byte0);
    SPI.transfer(byte1);
    // Disable SPI communications
    digitalWrite(cs,HIGH);
}

// ----------------------------------------------------------------------------
// MCP4822::off_A
//
// Turn off dac A
// ----------------------------------------------------------------------------
void MCP4822::off_A() {
    off(MCP4822_DAC_A);
}

// ----------------------------------------------------------------------------
// MCP4822::off_B
//
// Turn off dac B
// ----------------------------------------------------------------------------
void MCP4822::off_B() {
    off(MCP4822_DAC_B);
}

// ----------------------------------------------------------------------------
// MCP4822::off_AB
//
// Turn off dac A and B
// ----------------------------------------------------------------------------
void MCP4822::off_AB() {
    off_A();
    off_B();
}

#endif // WITH_AOUT

// ----------------------- end MCP4822 library

typedef uint32_t pulsenumber_dtype; /* 2**32 @100Hz = 497 days */

struct timed_sample {
    uint8_t value; /* value of arbitrary data */
    pulsenumber_dtype pulsenumber;
    uint16_t ticks;
};

// Pin numbers -----------------------------------------------------------------
const unsigned short TrigPin = 9;
const unsigned short LEDPin = 2;
#ifdef WITH_AOUT
const unsigned short AOUT_CS = 10;
const unsigned short AOUT_LDAC = 7;
#endif

// Global variables ------------------------------------------------------------
volatile pulsenumber_dtype pulsenumber=0;
    // ---- set TCCR1B ----------
    // high bits = 0,0,0
    // WGM13, WGM12 = 1,1
    // CS1 = 0,1,0 (starts timer1 CS=8) (clock select)
uint8_t tccr1b_when_running = 0x18; //stopped. started in setup()
#ifdef WITH_AOUT
MCP4822 analogOut = MCP4822(AOUT_CS,AOUT_LDAC);
#endif

UDEV udev(Serial);

bool trigger_output_enabled = true;

static inline void set_trigger_output_enabled(bool enabled) {
    trigger_output_enabled = enabled;
    if (enabled) {
        // Connect Timer1 OC1A to the physical trigger pin.
        // COM1A1:0 = 1,0 means clear OC1A on compare match in fast PWM mode.
        TCCR1A = (TCCR1A & ~((1 << COM1A1) | (1 << COM1A0))) | (1 << COM1A1);
        digitalWrite(LEDPin, LOW);
    } else {
        // Disconnect Timer1 OC1A from pin 9 while keeping Timer1 running.
        // This lets the clock model stabilize without emitting camera triggers.
        TCCR1A &= ~((1 << COM1A1) | (1 << COM1A0));
        digitalWrite(TrigPin, LOW);
        digitalWrite(LEDPin, HIGH);
    }
}

// Interrupt service routine for timer1 compare -------------------------------
ISR(TIMER1_COMPA_vect)
{
    pulsenumber++;
}

// Setup timer1 ----------------------------------------------------------------
void setup_timer1(uint8_t tccr1b, uint16_t icr1) {
    tccr1b_when_running = tccr1b;

    cli();

    // Set output compare to generate trigger pulse width
    OCR1A = 0x03e8;

    // Set TOP
    ICR1 = icr1;

    // ---- set TCCR1A ----------
    // set Compare Output Mode for Fast PWM, with TOP in ICR1
    // COM1A1:0 = 1,0 clear OC1A on compare match
    // COM1B1:0 = 1,0 clear OC1B on compare match
    // WGM11, WGM10 = 1,0
    TCCR1A = 0xAA;
    TCCR1B = tccr1b;

    TIMSK1 |= (1 << OCIE1A);

    sei();
}

// Standard arduino setup function ---------------------------------------------
void setup() {
    udev.begin();
    udev.serial_handshake();   //blocks for 5 seconds by default

    SPI.setDataMode(SPI_MODE0);
    SPI.setBitOrder(MSBFIRST);
    SPI.setClockDivider(SPI_CLOCK_DIV8);
    SPI.begin();

#ifdef WITH_AOUT
    analogOut.setGain2X_AB();
#endif

    pinMode(LEDPin, OUTPUT);
    pinMode(TrigPin, OUTPUT);

    // start serial port at 115200 bps:
    Serial.begin(115200);

    digitalWrite(LEDPin, HIGH);

    // Start Timer1 at 25 fps with physical trigger output enabled by default.
    // E0 can still blank the output without stopping Timer1 or resetting pulsenumber.
    setup_timer1(0x1B, 0x2710);
    set_trigger_output_enabled(true);
}

// Send data with our simple protocol to the host computer ---------------------
static char Serial_read_blocking() {
    while (Serial.available() == 0) {
        delay(10);
    }
    return Serial.read();
}

static inline void send_data_string(String* s, const char header) {
    uint8_t N = s->length();

    Serial.write(header);
    Serial.write(N); // payload size
    uint8_t chksum=0;
    char next_byte;
    for (uint8_t i=0; i< N; i++) {
        next_byte = s->charAt(i);
        chksum += next_byte;
        Serial.write(next_byte);
    }
    Serial.write(chksum);
}

static inline void send_data(const struct timed_sample samp, const char header) {

    /* This commented-out version does the same as below but with more
       overhead. Nevertheless, it can be used to verify the
       correctness of the send_data_string() function.

    const char * buf;
    buf = (const char*)&(samp);

    String out_buf="";

    for (uint8_t i=0; i< sizeof(timed_sample); i++) {
        out_buf += buf[i];
    }
    send_data_string(&out_buf, header);
    */

    const char * buf;
    Serial.write(header);
    Serial.write((char)sizeof(struct timed_sample)); // payload size
    buf = (const char*)&(samp);
    uint8_t chksum=0;
    for (uint8_t i=0; i< sizeof(struct timed_sample); i++) {
        chksum += buf[i];
        Serial.write(buf[i]);
    }
    Serial.write(chksum);
}

// Standard Arduino loop function. This gets repeatedly called at high rate ----
void loop() {
    if (Serial.available() >= 2) {
        static char cmd;
        static char value;

        cmd = Serial.read();
        value = Serial.read();

        if (cmd=='P') {
            // timestamp query
            static struct timed_sample timestamp_request;

            timestamp_request.value = value;

            uint8_t SaveSREG_ = SREG;   // save interrupt flag
            cli(); // disable interrupts

                timestamp_request.pulsenumber = pulsenumber;
                timestamp_request.ticks = TCNT1;

            SREG = SaveSREG_; // restore interrupt flags
            send_data(timestamp_request,'P');
        } else if (cmd=='V') {
            // version request
            static struct timed_sample version_request;

            version_request.value = 14;

            uint8_t SaveSREG_ = SREG;   // save interrupt flag
            cli(); // disable interrupts

                version_request.pulsenumber = pulsenumber;
                version_request.ticks = TCNT1;

            SREG = SaveSREG_; // restore interrupt flags
            send_data(version_request,'V');

            digitalWrite(LEDPin, LOW);

        } else if (cmd=='S') {
            // synchronization

            if (value=='0') {
                // stop clock, reset pulsenumber
                TCCR1B = 0x18;
                pulsenumber = 0;
                digitalWrite(LEDPin, HIGH);
            } else if (value=='1') {
                // start clock; physical output remains controlled by E0/E1
                TCCR1B = tccr1b_when_running;
                digitalWrite(LEDPin, trigger_output_enabled ? LOW : HIGH);
            } else if (value=='2') {
                // stop clock
                TCCR1B = 0x18;
                digitalWrite(LEDPin, HIGH);
            }

        } else if (cmd=='E') {
            // Physical trigger output enable.
            // E0 disables/blank physical pulses while Timer1 keeps running.
            // E1 enables physical pulses from Timer1 OC1A.
            // This does not reset pulsenumber and does not stop the clock.
            if (value=='0') {
                set_trigger_output_enabled(false);
            } else if (value=='1') {
                set_trigger_output_enabled(true);
            }

        } else if (cmd=='T') {
            // TOP value
            uint8_t value0, value1;
            char prescaler_key;
            uint16_t new_icr1;

            if (value=='=') {
                value0 = Serial_read_blocking();
                value1 = Serial_read_blocking();
                prescaler_key = Serial_read_blocking();
                new_icr1 = ((uint16_t)value1 << 8) + value0;
                ICR1 = new_icr1;
                if (prescaler_key=='1') {
                    // prescaler = 8
                    tccr1b_when_running = 0x1A;
                } else if (prescaler_key=='2') {
                    // prescaler = 64
                    tccr1b_when_running = 0x1B;
                }
            }

        } else if (cmd=='O') {
            // AOUT values
            uint8_t aout0_0, aout0_1,   aout1_0, aout1_1;
            uint8_t aout_sequence;
            int aout0, aout1;

            if (value=='=') {
                aout0_0 = Serial_read_blocking();
                aout0_1 = Serial_read_blocking();
                aout0 = ((int)aout0_1 << 8) + aout0_0;

                aout1_0 = Serial_read_blocking();
                aout1_1 = Serial_read_blocking();
                aout1 = ((int)aout1_1 << 8) + aout1_0;

#ifdef WITH_AOUT
                analogOut.setValue_AB(aout0, aout1);
#endif
                aout_sequence = Serial_read_blocking();


            static struct timed_sample aout_confirm;

            aout_confirm.value = aout_sequence;

            uint8_t SaveSREG_ = SREG;   // save interrupt flag
            cli(); // disable interrupts

                aout_confirm.pulsenumber = pulsenumber;
                aout_confirm.ticks = TCNT1;

            SREG = SaveSREG_; // restore interrupt flags
            send_data(aout_confirm,'O');

            }

        } else if (cmd=='N') {
            udev.process(cmd, value);
        }

    }

}

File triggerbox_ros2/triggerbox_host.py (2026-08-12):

#!/usr/bin/env python3
import sys
import argparse
import numpy as np
import time
# import roslib; roslib.load_manifest('triggerbox')
# ? ros2

#import rospy
import rclpy
from rclpy.node import Node

from triggerbox_ros2.api import TriggerboxAPI
from triggerbox_ros2_interfaces.msg import TriggerClockModel, AOutVolts, AOutRaw, AOutConfirm, \
     TriggerClockMeasurement
# Hmm wow the response is a function that gets defined by the ROS framework.
# Let's hope it's the same in ROS 2.
from triggerbox_ros2_interfaces.srv import SetFramerate
from std_srvs.srv import SetBool, Trigger
from triggerbox_ros2.triggerbox_device import TriggerboxDevice

import std_msgs.msg

def _make_ros_topic(base, other):
    # ensure no start slash and one trailing slash
    # not sure what this is all about...
    if base[0] == '/':
        base = base[1:]
    if base[-1] == '/':
        base = base[:-1]

    return base + '/' + other

class TriggerboxHost(TriggerboxDevice, TriggerboxAPI, Node):
    '''an in-process version of the triggerbox client with identical API
       porting to ROS2 - added Node as third multiple super, so prior code
       see first two supers first. Hopefully they dont mask any ROS2 node stuff.'''
    def __init__(self, device,ros_topic_base='~'):
        # Node.__init__('triggerbox_host')
        # if above doesn't work could try below; goal is to call parent Node init:
        super(TriggerboxAPI,self).__init__('triggerbox_host')
        
        self._gain = np.nan
        self._offset = np.nan
        self._expected_framerate = None
        self._output_enabled = False

        self.declare_parameter('output_enabled_on_start', True)
        self.declare_parameter('default_fps', 100.0)

        self.pub_time = self.create_publisher(
                                TriggerClockModel,
                                _make_ros_topic(ros_topic_base,'time_model'),
                                10)
        # This quality of service roughly emulates latch=True from ROS1 happarently.
        # https://pypi.org/project/rosros/
        qos = rclpy.qos.QoSProfile(depth=2,
                 durability=rclpy.qos.DurabilityPolicy.TRANSIENT_LOCAL)
        self.pub_rate = self.create_publisher(
                                std_msgs.msg.Float32,
                                _make_ros_topic(ros_topic_base,'expected_framerate'),
                                qos)
        self.pub_output_enabled = self.create_publisher(
                                std_msgs.msg.Bool,
                                _make_ros_topic(ros_topic_base,'output_enabled'),
                                qos)
        self.pub_raw = self.create_publisher(
                                TriggerClockMeasurement,
                                _make_ros_topic(ros_topic_base,'raw_measurements'),
                                10)
        self.pub_aout_confirm = self.create_publisher(
                                AOutConfirm,
                                _make_ros_topic(ros_topic_base,'aout_confirm'),
                                10)
        # hmm will this pass device to Node?
        # Ok TriggerboxDevice takes on input arg to __init__ which is device
        # TriggerboxAPI has no __init__ so this was supposed to his the dev.
        super(TriggerboxHost,self).__init__(device)

        self.set_trig_sub = self.create_subscription(
                std_msgs.msg.Float32,
                _make_ros_topic(ros_topic_base,'set_triggerrate'),
                self._on_set_triggerrate,
                10)
        self.pause_reset_sub = self.create_subscription(
                std_msgs.msg.Float32,
                _make_ros_topic(ros_topic_base,'pause_and_reset'),
                self._on_pause_and_reset,
                10)
        self.aout_volts_sub = self.create_subscription(
                AOutVolts,
                _make_ros_topic(ros_topic_base,'aout_volts'),
                self._on_aout_volts,
                10)
        self.aout_raw_sub = self.create_subscription(
                AOutRaw,
                _make_ros_topic(ros_topic_base,'aout_raw'),
                self._on_aout_raw,
                10)
        self.set_framerate_srv = self.create_service(
                SetFramerate,
                _make_ros_topic(ros_topic_base,'set_framerate'),
                self._on_set_framerate_service)
        self.set_output_enabled_srv = self.create_service(
                SetBool,
                _make_ros_topic(ros_topic_base,'set_output_enabled'),
                self._on_set_output_enabled_service)
        self.enable_output_srv = self.create_service(
                Trigger,
                _make_ros_topic(ros_topic_base,'enable_output'),
                self._on_enable_output_service)
        self.disable_output_srv = self.create_service(
                Trigger,
                _make_ros_topic(ros_topic_base,'disable_output'),
                self._on_disable_output_service)
        self.start_clock_srv = self.create_service(
                Trigger,
                _make_ros_topic(ros_topic_base,'start_clock'),
                self._on_start_clock_service)
        self.stop_clock_srv = self.create_service(
                Trigger,
                _make_ros_topic(ros_topic_base,'stop_clock'),
                self._on_stop_clock_service)

        # emit expected frame rate every 5 seconds
        self.timer = self.create_timer(5.0, self._on_emit_framerate)
        
        rclpy.logging.set_logger_level('/triggerbox_host',rclpy.logging.LoggingSeverity.DEBUG)

    def _on_set_triggerrate(self,_msg):
        self.get_logger().info('triggerbox_host: _on_set_triggerrate %s'%_msg.data)
        self.set_triggerrate(_msg.data)

    def _on_pause_and_reset(self,_msg):
        self.get_logger().info('triggerbox_host: _on_pause_and_reset %s'%_msg.data)
        self.pause_and_reset(_msg.data)

    def _on_aout_volts(self,_msg):
        self.get_logger().info('triggerbox_host: _on_aout_volts %s'%_msg)
        self.set_aout_ab_volts(_msg.aout0,_msg.aout1)

    def _on_aout_raw(self,_msg):
        self.get_logger().info('triggerbox_host: _on_aout_raw %s'%_msg)
        self.set_aout_ab_raw(_msg.aout0,_msg.aout1)

    def _on_set_framerate_service(self, request, response):
        self.set_frames_per_second_blocking(request.data)
        return response

    def _on_set_output_enabled_service(self, request, response):
        self.set_output_enabled(request.data)
        response.success = True
        response.message = 'trigger output enabled=%s' % bool(request.data)
        return response

    def _on_enable_output_service(self, request, response):
        self.enable_output()
        response.success = True
        response.message = 'trigger output enabled'
        return response

    def _on_disable_output_service(self, request, response):
        self.disable_output()
        response.success = True
        response.message = 'trigger output disabled'
        return response
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

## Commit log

2024-03-15 Added new hardware info for 2024 spence lab triggerbox designs
    [digikey2024-02-12T144911.xlsx, triggerbox_BOM.xlsx, triggerbox_shield_buffers.kicad_pcb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]
2024-03-15 pdfs of schematics
2024-04-05 well it gets to crashing because no /dev/ttyUSB0 in multipass...
    [triggerbox_client.py, triggerbox_device.py, triggerbox_host.py]
2024-04-10 Triggerbox_host works in ros2 with a physical arduino! Need to refix topic names, sure there will be many bugs. But runs!
    [triggerbox_device.py, triggerbox_host.py]
2024-04-12 fixed ros topic prefixes hopefully back to having node name
    [triggerbox_host.py]
2026-05-19 Add real-time thread priority setup instructions
    Added instructions for setting real-time thread priority in README.
2026-05-19 Update README with camera performance details
    Added notes on rebooting and performance of the camera system, including frame buffer details and sync information.
2026-05-20 fixed topic tilde things and node init.
    [triggerbox_host.py]
2026-05-21 Update README with Arduino firmware check instructions
    Added instructions for checking Arduino firmware version and using the handshaking protocol.
2026-05-21 Update README with firmware flashing instructions
    Added instructions for flashing Arduino and using triggerbox_host.
2026-05-21 executable script to get name and version from an attached triggerbox arduino.
2026-05-21 Revise README with updated triggerbox_host instructions
    Updated instructions for using triggerbox_host in ROS2 with arduino_udev setup steps.
2026-05-21 put copy of UDEV library required for firmware build here locally in this repo. do cp -r UDEV into Arduino/libraries/UDEV/UDEV.cpp,h and restart arduino IDE to build the firmware
2026-05-21 Update README with Arduino Nano flashing instructions
    Added detailed instructions for flashing Arduino Nano and using triggerbox with ROS2.
2026-05-21 Fix README formatting and enhance triggerbox instructions
    Corrected formatting and clarified instructions for using the triggerbox with Arduino and ROS2.
2026-05-21 Clarify Arduino naming instructions in README
    Updated instructions for setting the Arduino name and added example output.
2026-05-21 Testing and working pulse enable/disable, and also added --device input to triggerbox_host to specify /dev/trig9 etc.
2026-05-22 Update README with Arduino IDE 2 setup instructions
    Added instructions for setting up Arduino IDE 2 on Ubuntu, including installation steps and desktop entry creation.
2026-05-22 Fixed import of lcoal copy of arduinoudev. now require install of that onto system.
    [triggerbox_device.py]
2026-09-01 firmware/triggerbox: fix Arduino-Makefile board tag for modern boards.txt
    BOARD_TAG=nano328 no longer resolves: Debian/Ubuntu moved the bundled
    AVR core to the newer per-board .menu.cpu.<variant> boards.txt format
    years ago, so this flat legacy tag simply does not exist any more (make
    upload failed with -mmcu= empty, i.e. no CORE/VARIANT/MCU resolved at
    all). Use BOARD_TAG=nano with BOARD_SUB=atmega328old, the closest modern
    equivalent to what nano328 used to mean (57600 baud, ATmegaBOOT_168
    bootloader) -- matches this hardware, a Gravitech Nano 3.0 per
    hardware_sl_v1/datasheets. Confirmed: builds and flashes cleanly via
    make upload.
    Also add /dev/ttyACM* to ARDUINO_PORT alongside the exist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
